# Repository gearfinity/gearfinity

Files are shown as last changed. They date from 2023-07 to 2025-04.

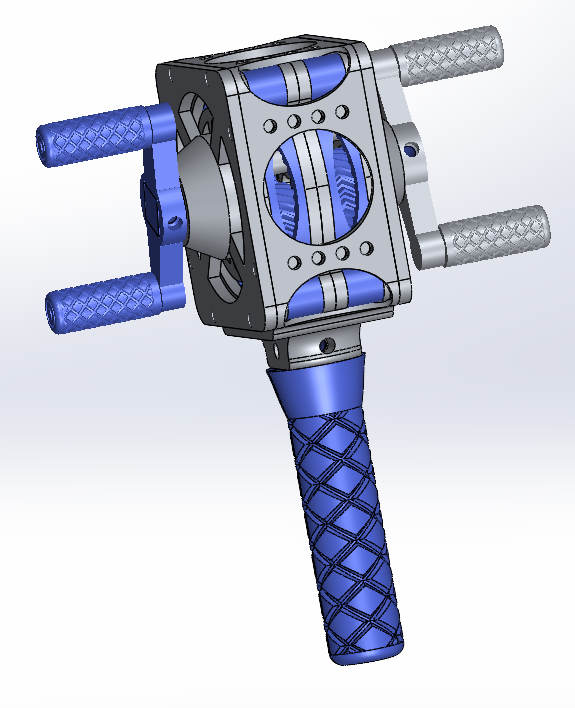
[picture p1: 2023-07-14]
crank_module/crank_module_1.png

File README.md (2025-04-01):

<p align="center">
  Gearfinity logo
</p>

# Gearfinity Project

Welcome to Gearfinity, your playground for boundless mechanical creations! Gearfinity is a modular and extensible 3D printing project, functioning as a comprehensive engineering kit. With Gearfinity, you can assemble intricate, fully functional mechanical constructs entirely from 3D printed parts – bearings, fasteners, and all. Ready to gear up?

<p align="center">
  planetary gear stage
  <br>
  <sub>The herringbone planetary gear stage. A core Gearfinity building block.</sub>
</p>

## A Note from the Founder

(not interested? [skip ahead](#-getting-started) to get started 😉)

Since I was a kid I've always been fascinated with modular construction sets. From Tinker Toys and Lincoln Logs to Legos and K'nex, I would get lost in the [challenge of building and creating](https://www.youtube.com/watch?v=j3P41ri6QZ8). My passion for designing and building later led me into studying robotics and [founding a team to compete in the NASA Lunabotics competition](https://www.alabamaastrobotics.com/) (the team went on to win many years of the competition). Building lunar excavator prototypes introduced me to the power of planetary gears and modular design. Around 2014 I purchased my first 3D printer: the legendary Da Vinci 1.0. I immediately fell in love with 3D printing. In designing robots I had picked up some CAD skills, and now I could almost instantly bring my designs into reality. The possibilities truly seemed endless!

Five years later in 2019 I suddenly became inspired to try to design a 3D printable bubble machine for my kids. I knew I wanted to use planetary gears somehow so I dove into researching what others had designed. I found [lots of cool creations](#-acknowledgements), but all of them had something in common that bugged me: they all required extra (non-3D printed) parts. I LOVE the idea of bootstrapping a creation without any external dependencies (NASA calls this [In Situ Resource Utilization or ISRU](https://www.nasa.gov/isru/overview)), so pretty soon I was inspired to create my own 3D printable construction set combining my passion for my childhood toys with the knowledge I had gained from my years with robotics. Thus, Gearfinity was born!

It took a few years of iterating and tinkering but I'm proud to say the Bubble Machine Module is now a functioning reality! (Stay tuned for the official release 😉). Along the way I created several other fun "Modules" and had ideas for many more. I'm thrilled to finally share this project with the world and I hope you find it as fun, educational, and inspiring as I do. Thanks for joining me on this journey!

<p align="right">
  <sub>- Justin Headley</sub>
</p>

## Table of Contents

1. [🚀 Getting Started](#-getting-started)
2. [🧩 Modularity](#-modularity)
3. [⚠️ Safety Warning](#-safety-warning)
4. [💖 Join Our Community](#-join-our-community)
5. [📋 Parts List](#-parts-list)
6. [🤝 Contributing](#-contributing)
7. [📄 License](#-license)
8. [👏 Acknowledgements](#-acknowledgements)
9. [🏆 Awards and Recognition](#-awards-and-recognition)
10. [📧 Get in Touch](#-get-in-touch)

## 🚀 Getting Started

Your journey into the Gearfinity universe begins with a few essential tools and resources. Here's what you'll need:

1. **A 3D printer**: The cornerstone of your Gearfinity creations.

2. **A hard, flat edge**: Something like a small flathead screwdriver or a knife will come in handy for separating parts.

3. **Wire cutters/snips or needle-nose pliers** (recommended): These tools will be useful for removing (and sometimes inserting) pins.

Once you're equipped, it's time to print your first tool: the [pin tool](https://github.com/gearfinity/gearfinity/blob/main/tools/pin_tool.STL). This is our recommended device for inserting pins seamlessly.

In Gearfinity, a 'module' refers to a specific configuration of components that together form a fully functioning mechanism. Each module incorporates various Gearfinity parts (i.e. components) in a way that showcases a distinct mechanical function or interaction.

---

<p align="center">
  The main component for most modules is the planetary gear stage. Check out the video below to get started building!
</p>

<p align="center">
  <a href="https://www.youtube.com/watch?v=IewrQ3KnOlo">Planetary Stage Assembly Video</a>
</p>

---

Ready to get your hands dirty with your first module? Meet the [crank module](https://github.com/gearfinity/gearfinity/blob/main/crank_module/README.md) – an excellent starting point for all aspiring Gearfinity builders. This module is meant to showcase some of the core features of Gearfinity in a simple way, so check it out!

<table>
  <tr>
    <td>
      <!-- This is the code to include your GIF. -->
      Crank module gif
    </td>
    <td>
      <!-- This is the code to embed your YouTube video. -->
      <a href="https://www.youtube.com/watch?v=n-d26yRk0Yk" target="_blank">
        YouTube Video
      </a>
    </td>
  </tr>
</table>

Remember, patience is key when it comes to assembly. So, take your time, enjoy the process, and watch as your mechanical masterpiece comes to life!

## 🧩 Modularity

Gearfinity acts as a construction set, which means modules can be quickly converted from one to another. The demo below shows how the crank module can be converted into a fan module in just a few steps.

<p align="center">
  <br>
  modularity demo
  <br>
  <sub>Modular modules!</sub>
</p>

## ⚠️ Safety Warning
While Gearfinity is designed for educational and recreational use, it's important to remember that the modules can generate high speeds and/or high torque due to the nature of the planetary gears and moving components.

Please exercise caution when assembling and operating the modules. Here are a few safety tips:

- Always keep your fingers and any loose clothing away from the moving parts to avoid injury.
- Avoid running the modules at high speeds for extended periods as it can lead to wear and potential breakage.
- Gearfinity modules are not toys. They should not be used by children without direct adult supervision.

Remember, safety first! Enjoy your Gearfinity experience responsibly.

## 💖 Join Our Community

Interested in becoming a part of the Gearfinity universe? Join our community to stay updated and get exclusive access to new content! By signing up, you'll gain:

- **Latest Updates:** Stay informed about new projects and developments.
- **Early Access:** Be the first to access new 3D models and modules.
- **Exclusive Tutorials:** Receive tips and guides to enhance your 3D printing skills.
- **Community Engagement:** Connect with fellow enthusiasts in our private Discord channel.
- **Monthly Newsletters:** Get featured builds and community highlights delivered to your inbox.

Learn more and join the Gearfinity community at [https://gearfinity.xyz](https://gearfinity.xyz).

## 📋 Parts List

You can view the current parts list table [here](https://docs.google.com/spreadsheets/d/158TpOWADwtF0e0_Nwcch7mfOSl0_y_dtp3eGY885oxw/edit?usp=sharing).
## 🤝 Contributing

Community and collaboration are the cornerstones of Gearfinity. If you're keen on contributing, check out our guidelines. Together, let's push the boundaries of what we can create!

## 📄 License

Embrace the freedom of creation! All Gearfinity models are free and open-source. Create, modify, and enjoy to your heart's content!

## 👏 Acknowledgements

A heartfelt thank you to all Gearfinity contributors, users, and supporters. You're the driving force behind our constantly turning gears!

### The shoulders of giants...

Gearfinity takes direct inspiration from many different designs and projects shared by others and would certainly not be possible with out their amazing contributions. Below you can find links to these foundational creations.

- [Getriebe Bibliothek für OpenSCAD / Gears Library for OpenSCAD](https://www.thingiverse.com/thing:1604369)
- [Turbine Propeller Fan Generator v2](https://www.thingiverse.com/thing:3874607)
- [Pin Connectors V3](https://www.thingiverse.com/thing:33790/files)
- [New 608 Bearing Concept: Conical Geometry Bearings](https://www.thingiverse.com/thing:4628063)
- [Planetary gear](https://www.thingiverse.com/thing:264769)
- [Mechanical Fan with planetary gears](https://www.thingiverse.com/thing:2058267)
- [Stackable Planetary Gear Mechanism (Reducer)](https://www.thingiverse.com/thing:1727833)

## 🏆 Awards and Recognition
**Gearfinity Fan Module: Elegoo x All3DP Summer Design Contest 2023 Winner**

We're honored to have our work recognized by Elegoo and All3DP, two leading names in the 3D printing industry. This award is not just a celebration of what we've achieved, but a springboard for what's to come.

Award: [First Prize, Elegoo x All3DP Summer Design Contest 2023](https://all3dp.com/4/elegoo-x-all3dp-summer-design-contest-wraps-up-with-amazing-creative-entries-ad/)

What's Next? This is just the beginning. Stay tuned for exciting new developments as we continue to innovate and expand the possibilities of 3D printed engineering.

## 📧 Get in Touch

Have questions or suggestions? Eager to share your latest creation? We're all ears! Feel free to open up an issue, join the community at https://gearfinity.xyz, or message us directly at gearfinity3d@gmail.com

## 🌟 Like what you see?

Please give us a star!

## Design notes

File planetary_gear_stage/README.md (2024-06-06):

# Planetary Gear Stage

Welcome to the Gearfinity Planetary Gear Stage! This model is a core building block for many of our modular mechanical constructs. Designed to be fully 3D printed, the planetary gear stage showcases the power and versatility of Gearfinity creations.

<p align="center">
  planetary gear stage
  <br>
  <sub>The herringbone planetary gear stage. A core Gearfinity building block.</sub>
</p>

Building the Planetary Gear Stage, you'll explore the mechanics of planetary gears and their applications in various projects. This stage is not just a standalone model; it forms the basis for many advanced Gearfinity modules.

---

#### Key Features:
- **Fully 3D Printed:** No additional supports or external parts needed.
- **Core Component:** Essential for building many Gearfinity modules.
- **Educational and Fun:** Learn about the mechanics of planetary gears through hands-on experience.

#### Assembly Instructions:
1. **Print the Parts:** Download and print all necessary STL files (watch the video for part quantities).
2. **Prepare for Assembly:** Gather a small flathead screwdriver or knife for separating parts, and wire cutters/snips or needle-nose pliers for removing pins.
3. **Follow the Video:** Watch the [Planetary Gear Stage Assembly Video](https://www.youtube.com/watch?v=IewrQ3KnOlo) for step-by-step instructions.
4. **Enjoy Your Creation:** Once assembled, experiment with the gear stage or integrate it into larger Gearfinity modules.

#### Join the Gearfinity Community:
Interested in becoming a part of the Gearfinity universe? Join our community to stay updated and get exclusive access to new content! By signing up, you'll gain:

- **Latest Updates:** Stay informed about new projects and developments.
- **Early Access:** Be the first to access new 3D models and modules.
- **Exclusive Tutorials:** Receive tips and guides to enhance your 3D printing skills.
- **Community Engagement:** Connect with fellow enthusiasts in our private Discord channel.
- **Monthly Newsletters:** Get featured builds and community highlights delivered to your inbox.

Learn more and join the Gearfinity community at [https://gearfinity.xyz](https://gearfinity.xyz).

So, ready to dive into the mechanics of planetary gears with Gearfinity? Let's get started!

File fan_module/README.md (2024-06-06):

# The Fan Module

Welcome to the Fan Module! This model takes the foundational concepts introduced in the Crank Module and expands on them, highlighting the modular and extensible nature of Gearfinity's designs.

<p align="center">
  Fan module gif
</p>

Building the Fan Module, you'll see firsthand how different components can be swapped in and out to alter the functionality of your creation. The Fan Module is more than just a fun project—it's a lesson in the versatility of Gearfinity's system.

---

#### Key Features:
- **Fully 3D Printed:** No additional supports or external parts needed.
- **Modular Design:** Easily transform the Crank Module into the Fan Module.
- **Educational and Fun:** Learn about the modularity and extensibility of mechanical systems through hands-on experience.

#### Assembly Instructions:
1. **Print the Parts:** Download and print all necessary STL files (watch the video for part quantities).
  - HINT: You can build the Fan Module from scratch or start with the [Crank Module](https://github.com/gearfinity/gearfinity/blob/main/crank_module/README.md) to experience the modularity of the system.
2. **Prepare for Assembly:** Gather a small flathead screwdriver or knife for separating parts, and wire cutters/snips or needle-nose pliers for removing pins.
3. **Follow the Video:** Watch the [Fan Module Assembly Video](https://www.youtube.com/watch?v=oZlYVgYIprY) for step-by-step instructions.
4. **Enjoy Your Creation:** Once assembled, use the fan module to stay cool during hot summer days or integrate it into larger Gearfinity projects.

#### Join the Gearfinity Community:
Interested in becoming a part of the Gearfinity universe? Join our community to stay updated and get exclusive access to new content! By signing up, you'll gain:

- **Latest Updates:** Stay informed about new projects and developments.
- **Early Access:** Be the first to access new 3D models and modules.
- **Exclusive Tutorials:** Receive tips and guides to enhance your 3D printing skills.
- **Community Engagement:** Connect with fellow enthusiasts in our private Discord channel.
- **Monthly Newsletters:** Get featured builds and community highlights delivered to your inbox.

Learn more and join the Gearfinity community at [https://gearfinity.xyz](https://gearfinity.xyz).

So, ready to take your 3D printing skills to the next level with the Fan Module? Let's get started!

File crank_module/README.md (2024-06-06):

# The Crank Module

Welcome to the Crank Module, a delightful introduction to the wonders of Gearfinity's 3D printed mechanical marvels!

<p align="center">
  Crank module gif
</p>

This simple yet comprehensive model offers a hands-on exploration of some core Gearfinity components. By building the Crank Module, you'll get to understand:

- How the unique **fasteners/pins** function in assembling complex structures.
- How **planetary gear modules** integrate seamlessly with each other to form efficient gear systems.
- How various **input and output components** can interface with the planetary gear stages to bring about mechanical motion.

Start off by learning how to build planetary gear stages: [Planetary Gear Stage Assembly Video](https://www.youtube.com/watch?v=IewrQ3KnOlo)

Then check out this video to guide you through each step of the crank module assembly process: [Crank Module Assembly Video](https://www.youtube.com/watch?v=rEJv3zD0lIk)

While the Crank Module is an excellent starting point, it's just the beginning of what Gearfinity has to offer.

## 💖 Join Our Community

Interested in becoming a part of the Gearfinity universe? Join our community to stay updated and get exclusive access to new content! By signing up, you'll gain:

- **Latest Updates:** Stay informed about new projects and developments.
- **Early Access:** Be the first to access new 3D models and modules.
- **Exclusive Tutorials:** Receive tips and guides to enhance your 3D printing skills.
- **Community Engagement:** Connect with fellow enthusiasts in our private Discord channel.
- **Monthly Newsletters:** Get featured builds and community highlights delivered to your inbox.

Learn more and join the Gearfinity community at [https://gearfinity.xyz](https://gearfinity.xyz).

So, ready to crank up your 3D printing game with Gearfinity? Let's get started!

## Next up...The Fan Module

Ready to take what you've learned to the next level? The [Fan Module](https://github.com/gearfinity/gearfinity/blob/main/fan_module/README.md) is an excellent next step where you'll see firsthand the power of Gearfinity's swappable modular components. Check it out!

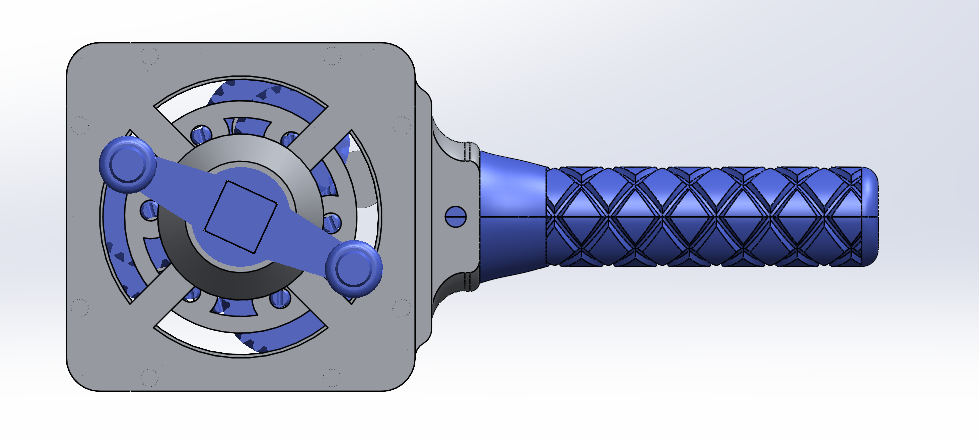
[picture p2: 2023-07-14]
crank_module/crank_module_2.png

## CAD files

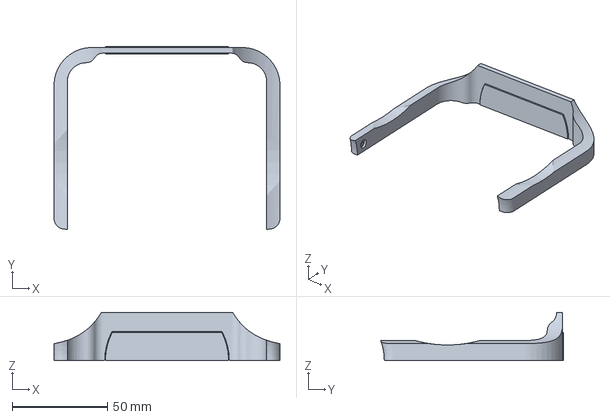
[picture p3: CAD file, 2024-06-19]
_all_parts/Part2^handle_plate_bracket_assembly.3MF
118.9 x 96.2 x 25.5 mm

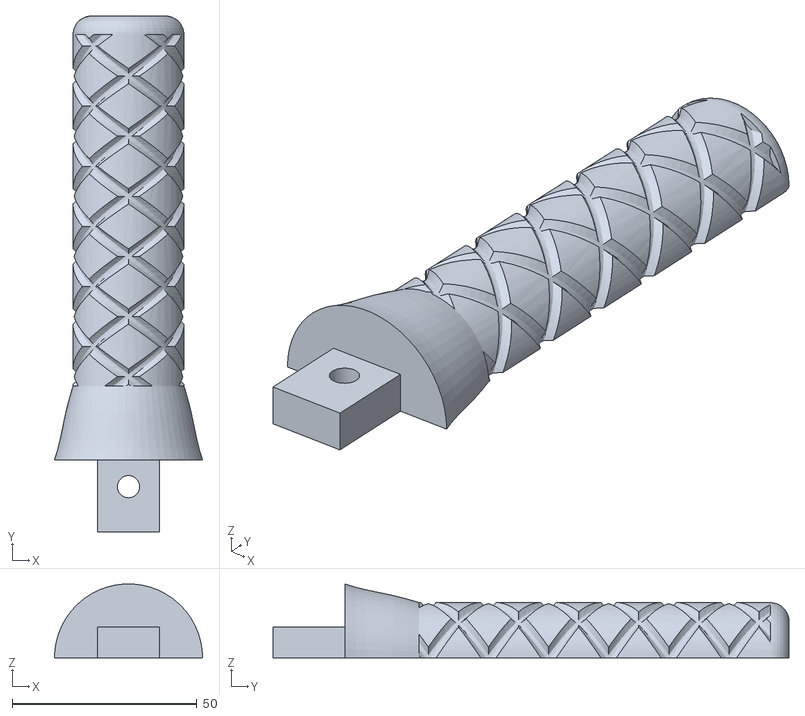
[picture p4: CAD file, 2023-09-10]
crank_module/handle-1.STL
40.1 x 139.5 x 20.0

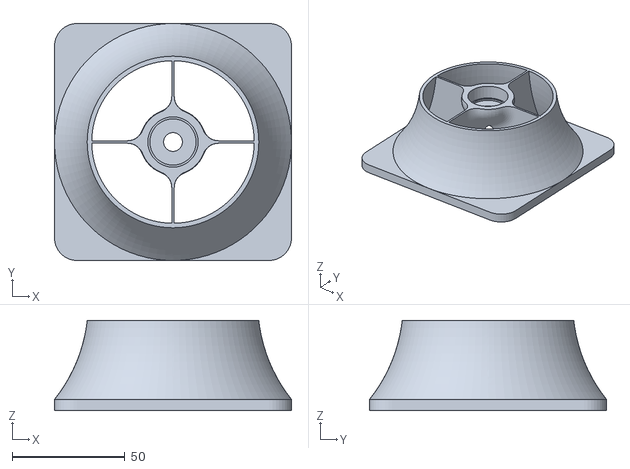
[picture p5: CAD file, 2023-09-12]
fan_module/fan_funnel-1.STL
105.0 x 105.0 x 40.0

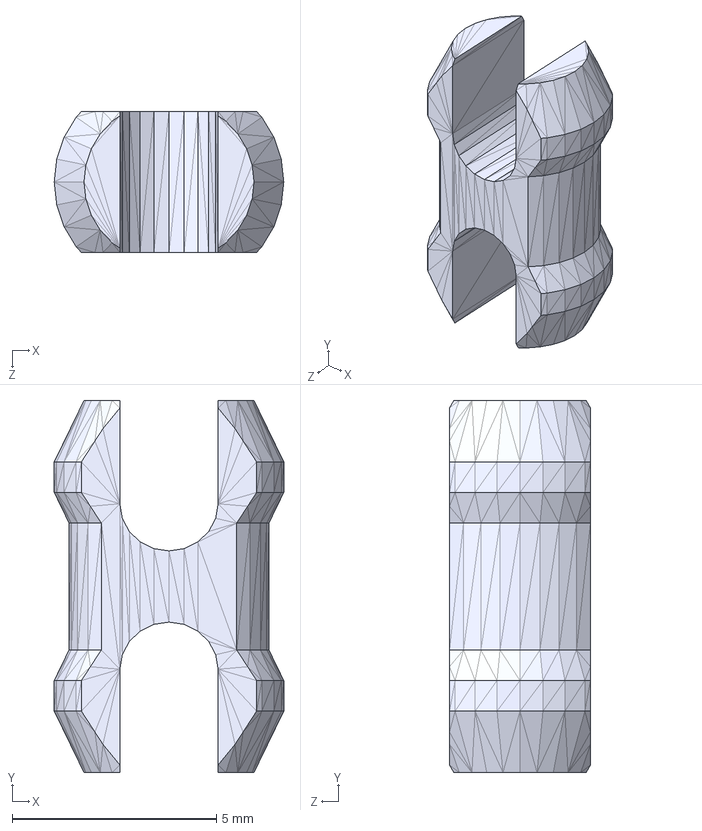
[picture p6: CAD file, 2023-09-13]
planetary_gear_stage/pin-1-1.STEP
5.62 x 9.10 x 3.45 mm

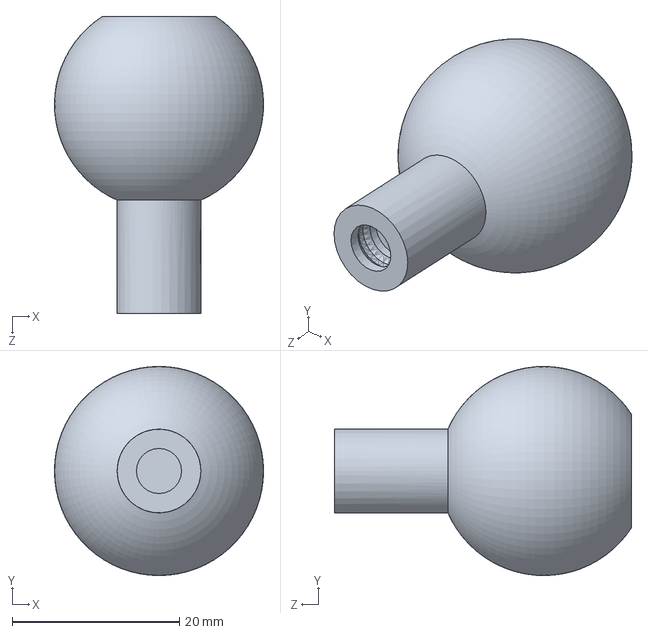
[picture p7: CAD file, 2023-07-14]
tools/pin_tool.SLDPRT
25.0 x 25.0 x 35.5 mm

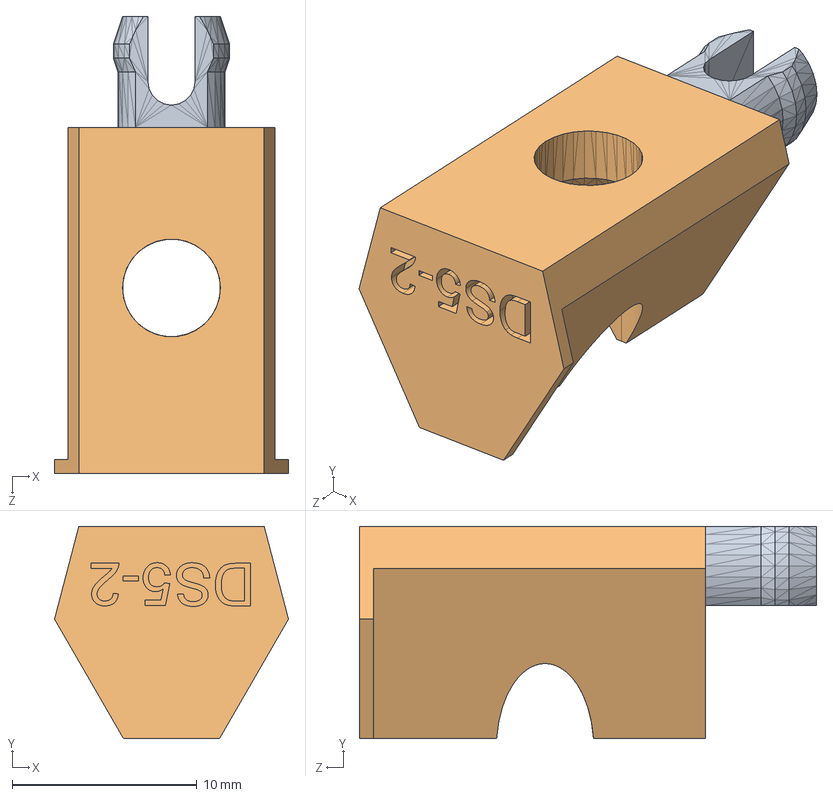
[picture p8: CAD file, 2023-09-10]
crank_module/drive_shaft_5-2.step
12.7 x 11.5 x 24.8 mm

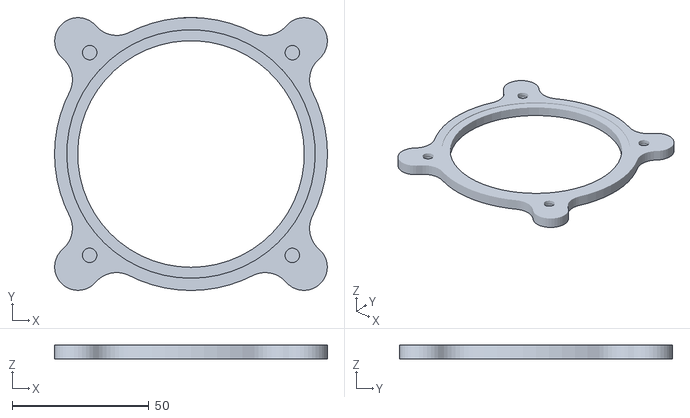
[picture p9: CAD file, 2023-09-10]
planetary_gear_stage/planetary_stage_cover-1.STL
100.0 x 100.0 x 5.00

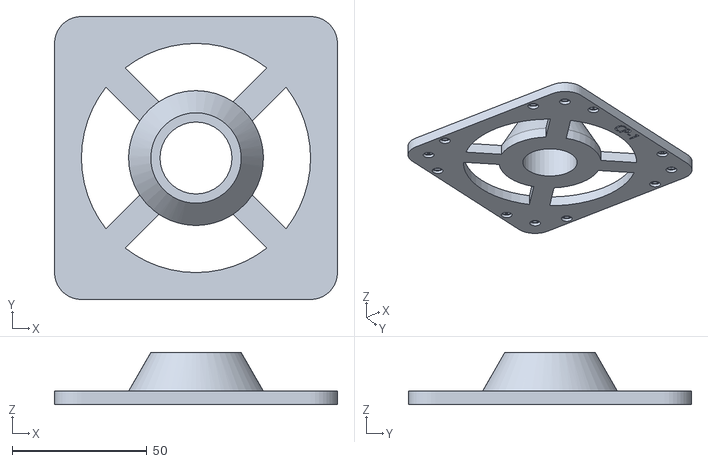
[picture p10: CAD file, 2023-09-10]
crank_module/crank_plate-1.STL
105.0 x 105.0 x 19.3

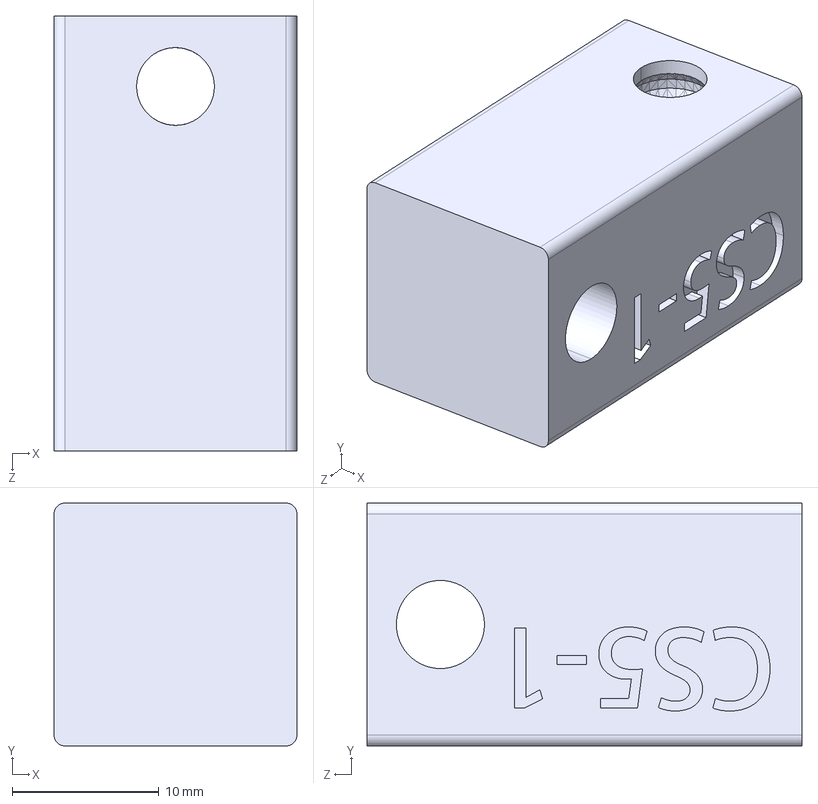
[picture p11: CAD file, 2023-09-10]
fan_module/crank_shaft_5-1.step
16.6 x 16.6 x 29.6 mm

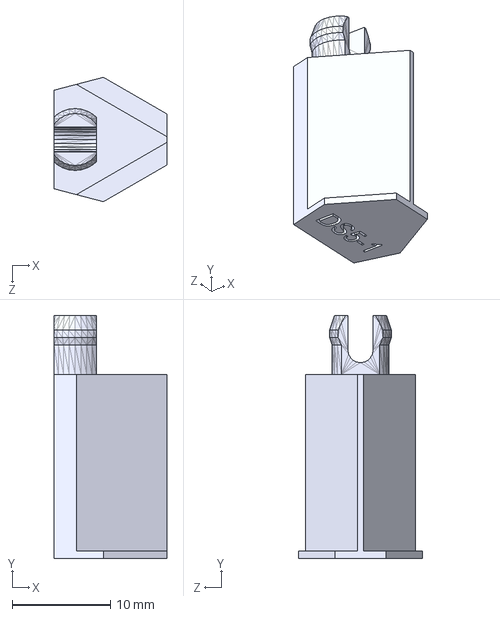
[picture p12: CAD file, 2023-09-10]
planetary_gear_stage/drive_shaft_5-1.step
11.5 x 24.8 x 12.7 mm

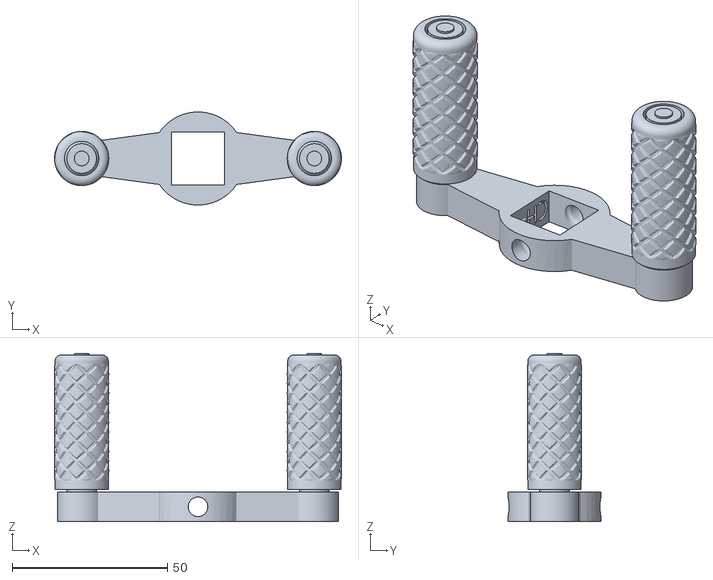
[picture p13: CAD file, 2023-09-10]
crank_module/crank_handle-1.STL
92.5 x 30.0 x 54.3

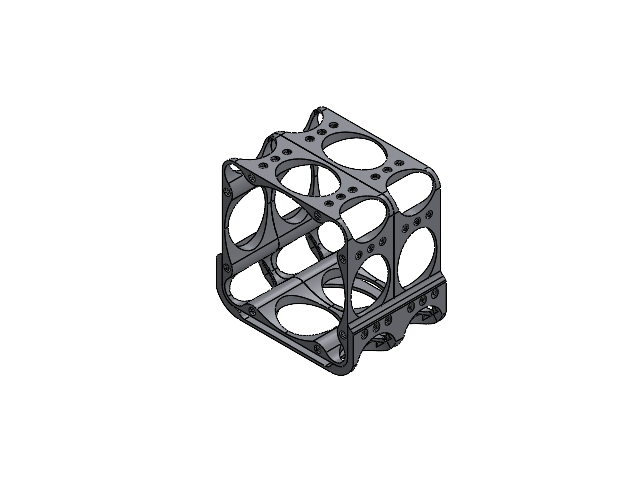
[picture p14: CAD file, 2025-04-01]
_all_parts/handle_plate_bracket_3_assembly.SLDASM
gearbox_cover_3_stage-1 x 2
handle_plate_bracket_3

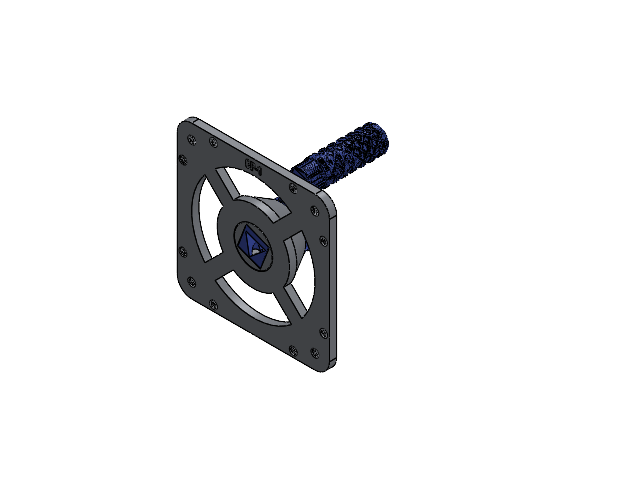
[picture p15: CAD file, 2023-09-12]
_all_parts/crank_input.SLDASM
crank_plate-1
crank_shaft_sleeve-1
crank_handle-2
crank_shaft_5-1

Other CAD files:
_all_parts/planetary_gear_core_5-2S05.STEP
_all_parts/roller_bearing-1.step
_all_parts/bevel_gear_15_drive.SLDPRT
_all_parts/planet_gear_sleeve_bearing-3.STEP
_all_parts/bevel_gear_15_drive.STL
_all_parts/blank_cylinder.SLDPRT
_all_parts/crank_arm-1.STL
_all_parts/crank_arm-2.STL
_all_parts/crank_handle-2.STL
_all_parts/crank_handle-grip-1.STL
_all_parts/crank_shaft_5-1.SLDPRT
_all_parts/crank_shaft_5-1.STL
_all_parts/crank_shaft_sleeve-1.SLDPRT
_all_parts/crank_shaft_sleeve-1.STL
_all_parts/crank_shaft_sleeve-1.step
_all_parts/crank_spindle-1.SLDPRT
_all_parts/crank_spindle-1.STL
_all_parts/drive_shaft_5-1.SLDPRT
_all_parts/drive_shaft_5-2.STL
_all_parts/drive_shaft_5-3-2.SLDPRT
_all_parts/drive_shaft_5-3-2.STL
_all_parts/drive_shaft_5-3.SLDPRT
_all_parts/drive_shaft_5-3.STL
_all_parts/drive_shaft_5-3.step
_all_parts/drive_shaft_5-4.SLDPRT
_all_parts/drive_shaft_5-4.STL
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

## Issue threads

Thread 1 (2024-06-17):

Recommendation - Provide 3mf file for PGC5-2S15 with separate objects

npanagop, 2024-06-17:
Hello,

Great idea, hope this takes off!

I just printed the first part of the planetary gear set (PGC5-2S15). I had issues with the gear teeth getting stuck to each other. I know this is my fault because I printed on a new material which I haven't tuned for my printer yet.

Despite that, I believe it would be convenient for testing to have a .3mf file (PrusaSlicer project) with the gears placed in their respective positions already but as separate objects. The user would be able to scale them by a few percents to improve tolerances.

Thank you.

gearfinity, 2024-06-17:
Excellent suggestion! I also plan on providing different pre-set tolerances to try. The "15" in the PGC5-2S15 actually represents 0.15 mm tolerance in the openscad model that generates them. I'm not sure how different it would be to manually scale the gears themselves (I'm no expert in gear mechanics) but I agree it would be a good option to have if the pre-set options don't work.

Also, in my own experience the biggest issue with the gears sticking is due to "elephant foot" on the first layer. I used to use a raft to fix this but my new printer is tuned well enough to print the first layer accurately.

gearfinity, 2024-06-17:
Yeah, I just checked and I do have a 0.10 mm tolerance option here:

_all_parts/planetary_gear_core_5-2S10.STL

Of course that's in the wrong direction for your case 😅 (the 0.15 mm is usually pretty loose for me)

I'll see if I can add a 0.20 mm option as well.

gearfinity, 2024-06-17:
Done! Just added the 3MF:

https://github.com/gearfinity/gearfinity/blob/main/_all_parts/planetary_gear_core_5-2S15.3MF

I tested it out in prusaslicer and scaling each gear individually (in the xy plane only) seemed to work great (however I didn't verify slicing or printing).

If you get a chance to play with this I would love to hear how it goes!

Closed 2024-06-17.

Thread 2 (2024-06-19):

Fan module: Weak point - Crank_Handle-2 STL

DillonSimeone, 2024-06-19:
Why is this little area thinner than the rest of the handle? It really weakens the Crank_Handle-2 STL, to an extent where it snapped within one minutes of using.

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

I cut it in the Bambu slicer, and adjusted it so it's like this:

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

This should be much more durable. Durability aside, this part would be improved if the handle was free-rotating.

gearfinity, 2024-06-19:
Ah, this is a great point that I've absent-mindedly left out of instructions. The handle is actually meant to be free rotating. After printing if you twist it directly around it's axis it should break free at the thin part. See the cross-section image below for better insight into how it is separate from the inner axle.

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

DillonSimeone, 2024-06-19:
Ah, wow! Nice.

Hmm... Maybe a ball joint would be more durable?

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

I could increase my infill to 100% and see how this shakes out. I probably printed this on the default setting of 15% infill. Seven hours until my printer finish printing the modified parts, too far in to pull out, kek.

gearfinity, 2024-06-19:
Looking good!

Yeah a higher infill could definitely help. I've got some beefier, multi-part crank handles in the works that won't break as easy (just require a little bit more assembly).

Thanks for the pics!

Closed 2024-06-19.

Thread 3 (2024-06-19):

Fan module: Weak point - Handle-1, Gearbox_cover and handle_plate

DillonSimeone, 2024-06-19:
I get that you was trying to make all of those parts printable without support, but sadly, as is, those parts kept coming apart really easily. I've sliced and modified the parts slightly in the Bambu slicer as you can see below:

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

This is what it looks like in my slicer with supports. Just 3g of supports. Meh.

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

Tried in other directions just in case.

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

DillonSimeone, 2024-06-19:
🤔 Have me wondering if the short pins and long pins isn't the ideal approach here... Maybe making lego-like assets that can be assembled in any slicer softwares, then printed out as one solid indestructible piece?

gearfinity, 2024-06-19:
Could you specify which parts are coming loose? The common problem I've run into is the handle plate coming off of the gearbox. I had designed a backet to prevent this but I just now got around to uploading it:

https://github.com/gearfinity/gearfinity/blob/main/_all_parts/handle_plate_bracket_half-1.STL

You can see how it's assembled here:

https://www.youtube.com/shorts/OGo2ZauXTeQ

DillonSimeone, 2024-06-19:
Oh wow, now this is ingenious! Keeping in line of the spirit of extreme modularity when not compromising too much on durability!

Yes, the plate was coming off constantly. I'm still printing... Halfway finished, the 3D printer got tangled when I was sleeping. Darn! My fault for putting a new reel in in total darkness with one arm.

gearfinity, 2024-06-19:
Haha, yeah in my experience so far the flexibility that modularity provides opens up opportunities to design parts in a way that actually capitalizes on the strengths of 3D printing.

For instance, the bracket as a single part would need to be printed standing up if no supports were used, like this:

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

This makes the bracket arms much more fragile as the grain would be perpendicular to the "length" of the part. But as two parts:

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

The layer grain and the arms are much stronger.

Also, having an "intended" print arrangement allows for built-in supports, which I much prefer over the slicer generated supports.

DillonSimeone, 2024-06-20:
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

Imagine the look on my face when I connected the new crank, only for it to explode like this when turned at full power, kek

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

This is really lending weight to your approach of going really modular... If a piece breaks, print out a new replacement and slam that in! Seems that there's a bad line going across everything I printed due to swapping 3D print filaments mid-print. Oof!

A quick sweep over an open flame ought do nicely for the new heavy-duty non-modular frame I made...

DillonSimeone, 2024-06-20:
ANYWAY. Glad that this got more modular parts shaking out of the modular bag! Durability issue resolved!

gearfinity, 2024-06-20:
@DillonSimeone great pics! Thanks for sharing 😄

Closed 2024-06-20.

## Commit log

2023-07-14 Initial commit (crank module)
    [blank_cylinder.SLDPRT, crank_shaft_5-1.SLDPRT, crank_shaft_5-1.step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]
2023-07-14 add tools
    [pin_tool.SLDPRT, pin_tool.STL]
2023-07-14 step to stl script and crank module stl files
    [crank_handle-1.SLDPRT.STL, crank_plate-1.SLDPRT.STL, crank_shaft_5-1.SLDPRT.STL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]
2023-07-14 Remove SLDPRT from stl names
    [crank_handle-1.SLDPRT.STL, crank_handle-1.STL, crank_plate-1.SLDPRT.STL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]
2023-07-14 fan module and move scripts
    [crank_handle-1.STL, crank_handle-2.STL, crank_input.SLDASM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]
2023-09-09 updated parts
    [drive_shaft_5-1.SLDPRT, drive_shaft_5-1.STL, drive_shaft_5-1.step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]
2023-09-09 adding missing core file
    [planetary_gear_core_5-2S15.STL, planetary_gear_core_5-2S15.step]
2023-09-10 updating orientation
    [drive_shaft_5-1.SLDPRT, drive_shaft_5-1.STL, drive_shaft_5-1.step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]
2023-09-10 fixing orientations
    [crank_handle-1.STL, crank_plate-1.STL, crank_shaft_5-1.SLDPRT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]
2023-09-10 fixing orientation and font
    [crank_handle-1.STL, crank_handle-2.STL, crank_input.SLDASM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]
2023-09-10 fixing orientation
    [drive_shaft_5-2.SLDPRT, drive_shaft_5-2.STL, drive_shaft_5-2.step]
2023-09-12 updated fan funnel
    [crank_input.SLDASM, fan_funnel-1.STL]
2023-09-13 new part: pin-1-1
    [pin-1-1.SLDPRT, pin-1-1.STEP, pin-1-1.STL]
2023-09-13 missing drive shaft 2 in crank module
    [drive_shaft_5-2.SLDPRT, drive_shaft_5-2.STL, drive_shaft_5-2.step]
2024-06-04 Add core model to fan folder
    [planetary_gear_core_5-2S15.step]
2024-06-04 add planetary gear stage folder and pin tool to other modules
    [drive_shaft_5-1.STL, drive_shaft_5-1.step, pin-1-1.STEP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]
2024-06-19 handle plate bracket
    [Part2^handle_plate_bracket_assembly.3MF, handle_plate_bracket_half-1.3MF, handle_plate_bracket_half-1.STL]
2024-06-19 update sld files
    [pin-1.SLDPRT, planetary_stage_cover-1.SLDPRT]
2024-07-01 added hook at the top of the bracket for a stronger lock
    [handle_plate_bracket_half-1.STL]
2024-07-01 step and 3mf
    [handle_plate_bracket_half-1.3MF]
2024-07-02 improved crank handle models
    [crank_arm-1.STL, crank_arm-2.STL, crank_handle-grip-1.STL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]
2024-07-02 input shaft with tighter fit
    [drive_shaft_5-3-2.SLDPRT, drive_shaft_5-3-2.STL]
2025-04-01 update parts
    [gearbox_cover_1_stage-1.STL, gearbox_cover_3_stage-1.STL, handle_plate-2.STL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]
2025-04-01 fix hpb3
    [handle_plate_bracket_3.STL]
2025-06-09 added clockwise fan prop
    [fan_prop_5C-1.SLDPRT, fan_prop_5C-1.STL, fan_prop_5CC-1.SLDPRT]
2026-06-26 Add Git LFS tracking for CAD/3D/media binaries
    Track SolidWorks (.SLDPRT/.SLDASM/.SLDDRW), STEP, STL, 3MF, and mp4
    files via Git LFS so large binary assets no longer bloat regular git
    history. Applies to files added going forward; existing history is
    unchanged.
2026-06-26 Add pin variants pin-1-2, pin-2-1, pin-2-2
    [pin-1-2.SLDPRT, pin-1-2.STEP, pin-1-2.STL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]
2026-06-26 Add planet gear sleeve bearing variants 2 and 3
    [planet_gear_sleeve_bearing-2.SLDPRT, planet_gear_sleeve_bearing-2.STEP, planet_gear_sleeve_bearing-2.STL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]
2026-06-26 Add bevel_gear_15_drive
    [bevel_gear_15_drive.SLDPRT, bevel_gear_15_drive.STL]
2026-06-26 Update roller_bearing-1
    [roller_bearing-1.SLDPRT, roller_bearing-1.STL, roller_bearing-1.step]
2026-06-26 Add planetary_gear_core_5-2S05
    [planetary_gear_core_5-2S05.SLDPRT, planetary_gear_core_5-2S05.STEP, planetary_gear_core_5-2S05.STL]
